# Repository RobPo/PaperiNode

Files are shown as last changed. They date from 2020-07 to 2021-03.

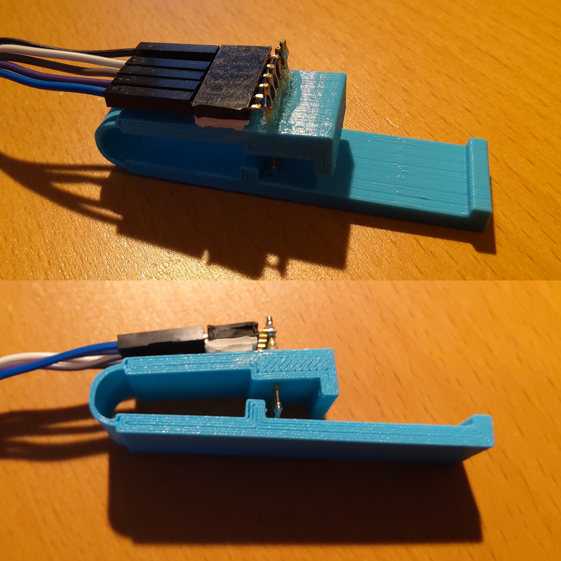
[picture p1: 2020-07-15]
3d/programming clip/programming_clip_2.jpg

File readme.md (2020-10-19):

Solar powered E-Paper Node for LoRaWAN
===============================================================

Welcome to the docs! This is an Arduino Library for PaperiNode, a TTN-connected 1.1” E-Paper Node which is powered by ambient light and thus energy-autark. 

paperinodes
[*PaperiNode*](https://twitter.com/Paperino_io)

Hardware specification (**[Datasheets](https://github.com/RobPo/paperinode/tree/master/datasheets)**):
-----------------------
- MCU: ATmega328pb (16MHz, 32KB FLASH, 2KB SRAM)
- External RTC: MCP7940M
- LoRa Chip: RFM95W, Antenna EU_863_870 or u.FL connector for external antenna
- EPD: 1.1" Plastic Logic, 148x70pixel
- Flash: Winbond W25X40Cl, 4Mbit
- Low power design: Deep Sleep 2.4uA
- PV cells: IXYS SLMD121H04L
- Energy-harvesting PMIC: E-Peas AEM10941 w/ MPPT
- Storage device: EDLC supercap 400mF

### Revisions

  
The second revision (black FPC) is the successor of the first edition (white FPC) and contains the following changes:
- Reduced deep sleep current
- SPI pins exposed on bottom side to connect external sensors etc.
- SPI flash added to store measurement data or upto seven pictures

How To Use
-------------------

### Installation

Please download and start the latest Arduino IDE. Select "Pololu A-star 328pb, 5V/16MHz" in the menu Tools/Board; if not available please add to File>Preferences>Additional Boards Manager URL the following source "https://files.pololu.com/arduino/package_pololu_index.json". Now please download and import the examples of this repository.

### Hardware hookup

To program PaperiNode you will need to connect a FTDI programmer (USB to Serial, available for ~3€ e.g. at eBay) to the exposed pins on the bottom side. The most reliable version is to solder a pin row and connect everything on a breadboard. Alternatively, its possible to connect the programmer  directly to the bottom pins (if needed in combination with a slight pressure) or to 3D-print your own pogo-pin based clamp (see below):
Programming the device

### E-Ink display library 'PL_microEPD'

Based on Adafruit GFX library, this version of 'PL_microEPD' enables the easy usage of the 1.1" EPD in combination with the used MCU ATmega328PB. Most work was done around coping with the limited available SRAM size while still exposing all the nice features of the screen. The following commands are available:

```C++
void begin();                                       // Initializes and clears the screen
void clear();                                       // Clears the framebuffer	
void printText(String text, int x, int y, int s);   // Write text to a defined position with size s
void loadFromFlash(int address=ADDR_FRAMEBUFFER, bool toPreviousBuffer=true);	   // Loads a previously stored pic from SPI flash
void fillRectLM(int16_t x, int16_t y, int16_t w, int16_t h, uint16_t color);           // Draws a filled rectangle
void update(int updateMode=EPD_UPD_FULL);           // Trigger an update with the framebuffer content
void end(void);                                     // De-init the screen to save power
```

The screen supports four different greylevels:

```C++
#define EPD_BLACK 0x00            // A black almost as dark as the night
#define EPD_DGRAY 0x01            // A darker gray
#define EPD_LGRAY 0x02            // A lighter gray
#define EPD_WHITE 0x03            // A white as bright as snow
```

The following update modes are available:
```C++
#define EPD_UPD_FULL  0x00            // Triggers a Full update, 4 GL, 800ms
#define EPD_UPD_PART  0x01            // Triggers a Partial update, 4 GL, 800ms
#define EPD_UPD_MONO  0x02            // Triggers a Partial Mono update, 2 GL, 250ms
```
### Examples

Now its time to get started! Ready to use examples can be found **[here](https://github.com/RobPo/paperinode/tree/master/examples)**:

- 01_SerialPrintDevEUI > Prints the individual Device EUI address to the serial console. 
- 02_Hello World 	   > Shows the first text on the epd screen.
- 03_SaveImgToFlash    > Shows how to store upto seven pictures in the flash memory.
- 04_MeasVScap 		   > Example which prints the measured voltage of the supercap storage device on the epd screen.
- 05_Minimal 		   > Demonstrates a simple counter, being updated everytime if there is sufficient energy harvested. The supercap voltage v_scap is measured minutely while the ATmega328pb processor is in deep sleep all remaining time. Triggering is done via external RTC to minimize current consumption during deep sleep phase. IF the voltage is charged above a certain limit (ie 4.2V), an image update is triggered. 
- 06_WeatherForecast   > Based on the previous demo,  a LoRa up- and downlink is added; the received payload is then shown on the screen.

Power consumption
-------------------

For this example the used energy is 0,7Joule (based on ABP with SF7 and 18byte payload within downlink). 

Projects
-------------------
Following demo projects are for your inspiration! What will you implement with PaperiNode? Tell us, we’ll love to add your project here!

weatherforecast

Where To Get
-------------------
PaperiNode is available at [tindie](https://www.tindie.com/products/robertposer/paperinode-solarpowered-e-paper-node-for-lorawan/)


License Information
-------------------

This library is **open source**!

Libraries used in this sketch are based on the LoRaWAN stack from IDEETRON/NEXUS, for more infos please check this great source: https://github.com/Ideetron/Nexus-Low-Power

Libraries used in this sketch around the ePaper and the Example sketches are created by Robert Poser, Jun 20th 2020, Dresden/Germany. 

Released under GNU Lesser General Public License, either version 3 of the License, or (at your option) any later version, check license.md for more information.

We invested time and resources providing this source code, please support open source hardware and software @Ideetron, @Adafruit, @Watterott, @Tindie and others.

If you like this project please [follow us on Twitter](https://twitter.com/paperino_io).
Having problems or have awesome suggestions? Contact us: paperino.display@gmail.com.

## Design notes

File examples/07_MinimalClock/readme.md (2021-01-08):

Example: 07_Clock demo
-------------------
Updates every five minutes. Should run around the clock if exposed to the window desk (battery-free).
Sketch optimized for low power usage on MCU and EPD level.



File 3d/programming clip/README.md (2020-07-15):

Build Instructions
==================

After printing, heat up the end to bend the clip open. Insert the Pogo PINs and heat it up again to bend it back.

Images
======
programming_clip_2

Thanks to SebastianHa for creating. https://github.com/sebastianha/lorapaper/tree/master/utils/programming%20clip

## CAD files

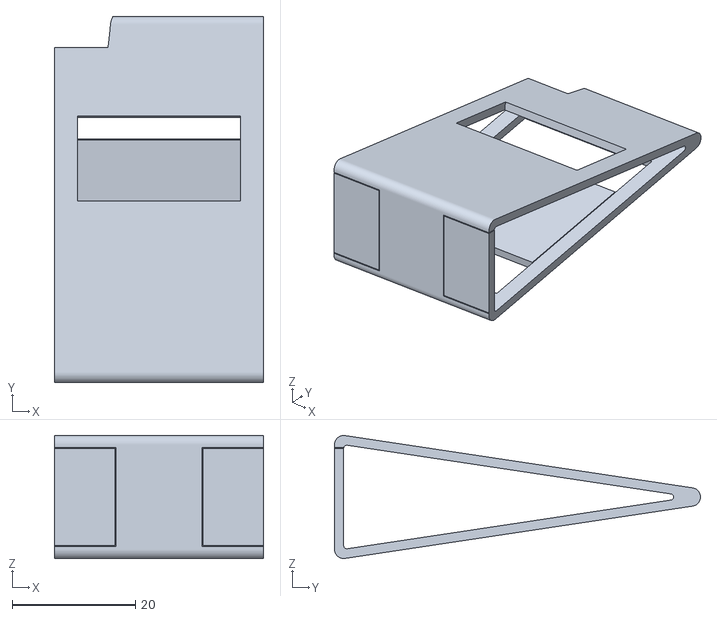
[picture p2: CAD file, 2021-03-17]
3d/housing/PaperiNode_V3_with_Breakaway.stl
34.0 x 59.5 x 20.0

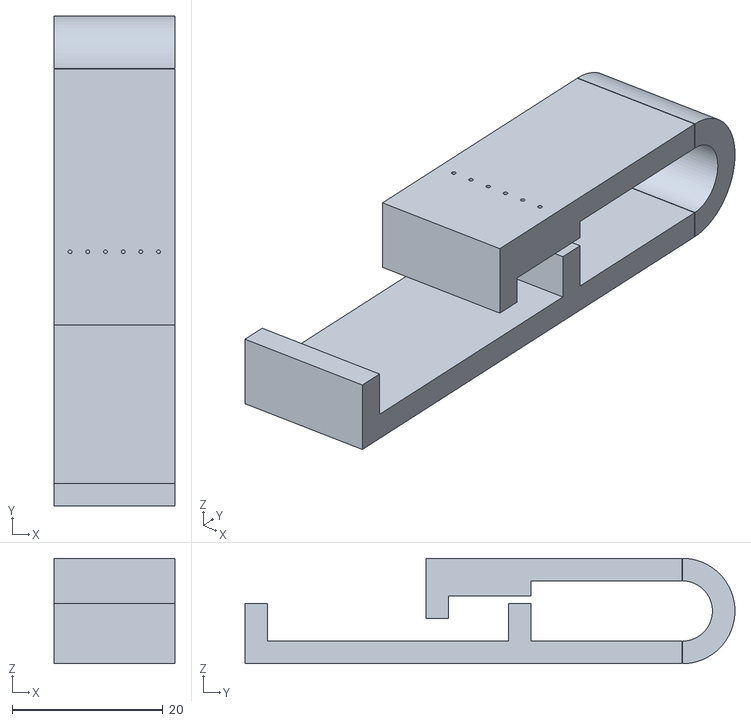
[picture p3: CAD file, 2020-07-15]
3d/programming clip/Paper Node Programming Clip.stl
16.0 x 65.0 x 14.0

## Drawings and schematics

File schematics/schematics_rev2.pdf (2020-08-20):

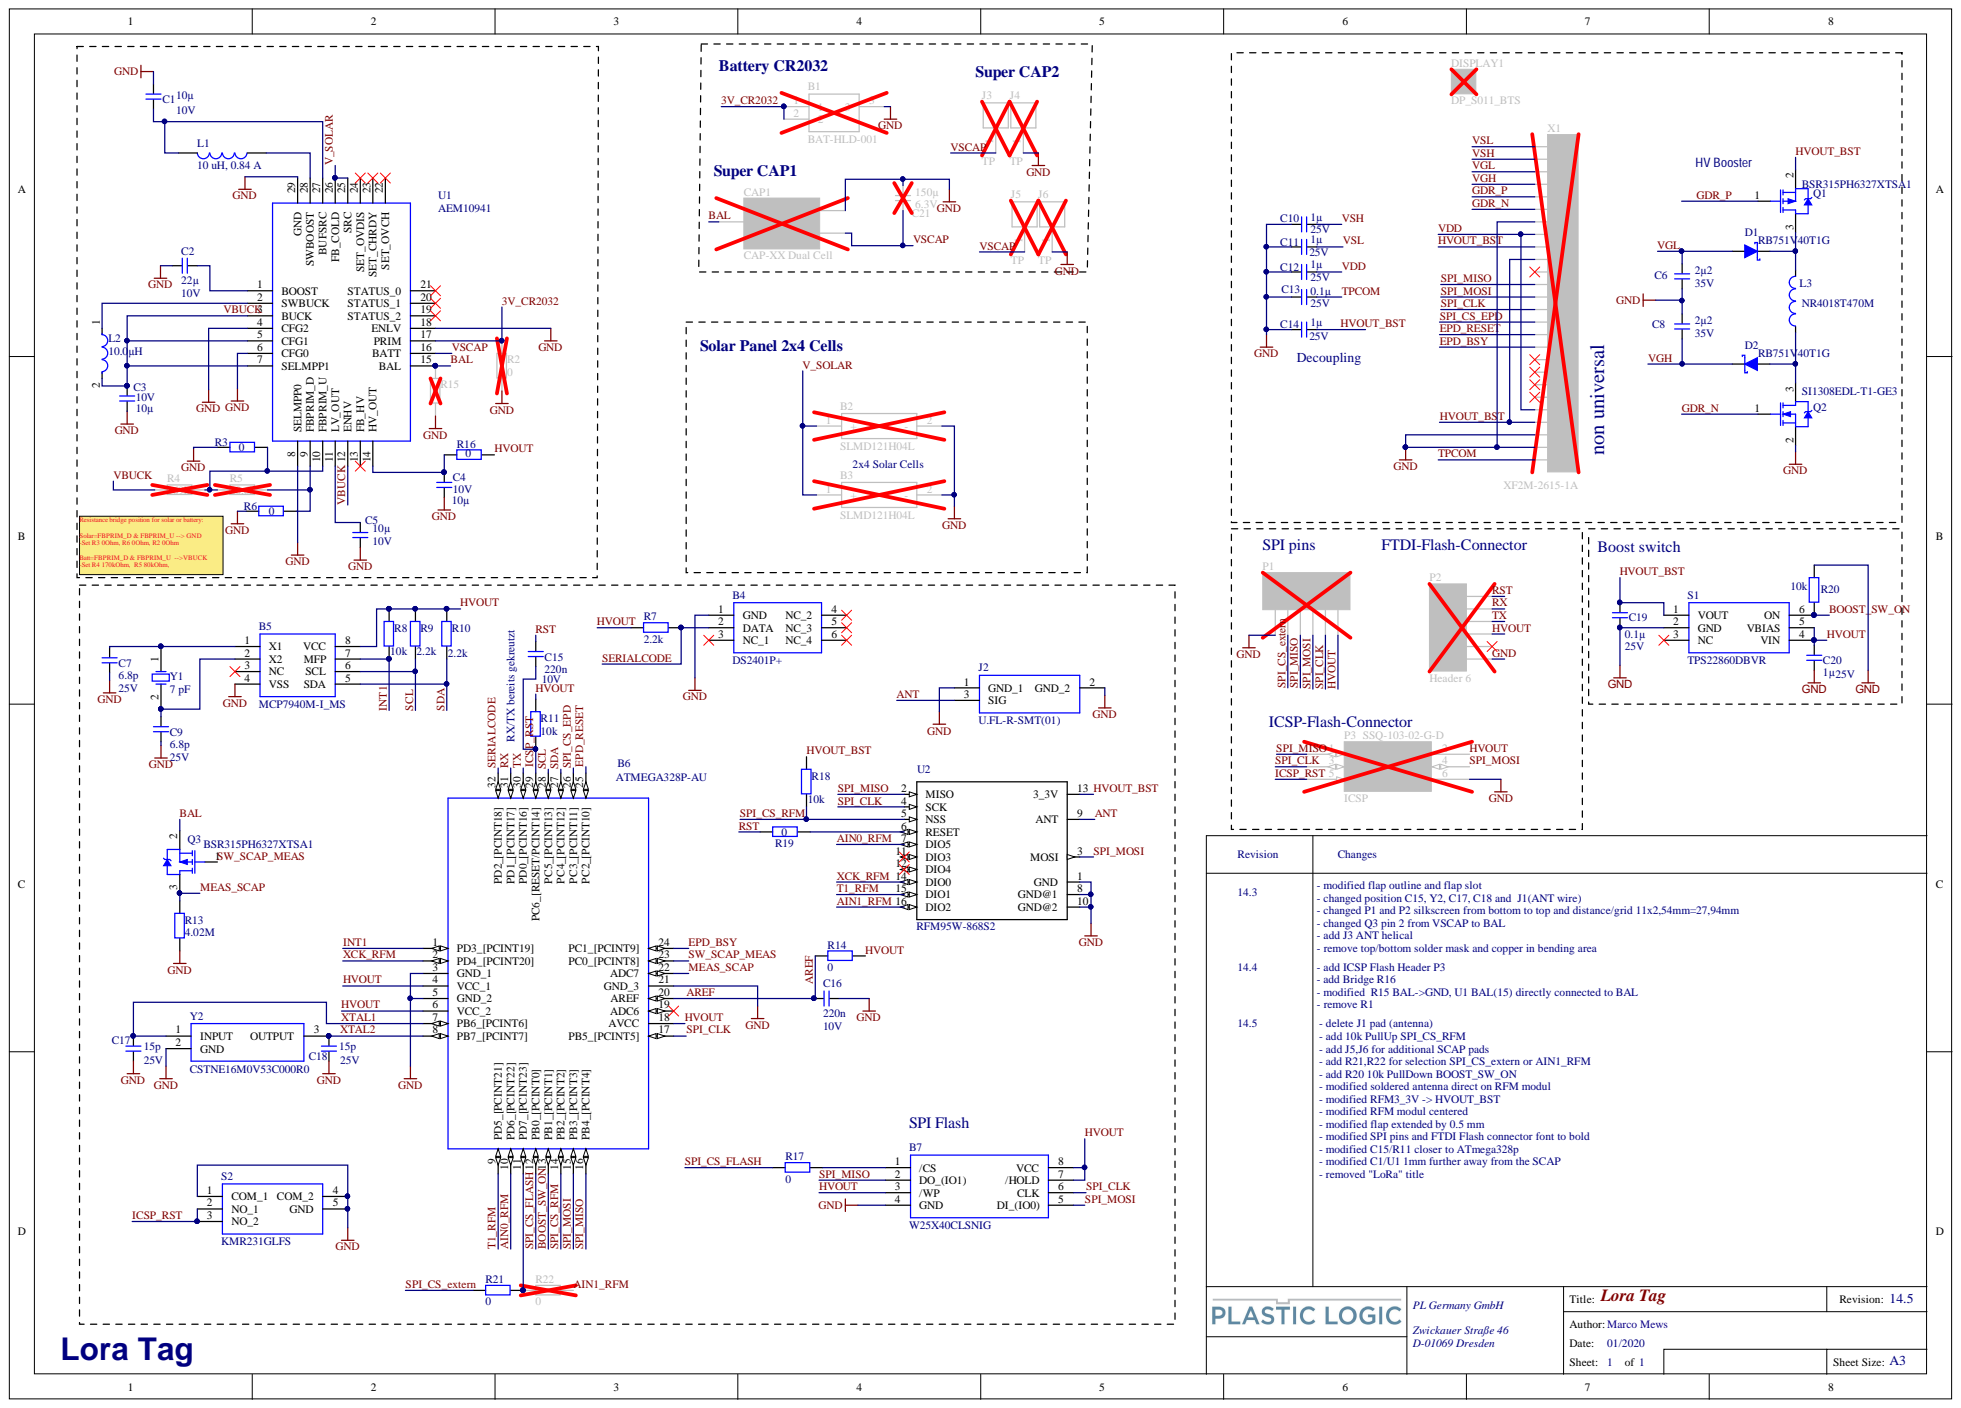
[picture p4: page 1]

CAP-XX Dual Cell

Resistance bridge position for solar or battery:

RX/TX bereits gekreutzt

- changed position C15, Y2, C17, C18 and J1(ANT wire)
- changed P1 and P2 silkscreen from bottom to top and distance/grid 11x2,54mm=27,94mm
- changed Q3 pin 2 from VSCAP to BAL
- add J3 ANT helical
- remove top/bottom solder mask and copper in bending area

- add Bridge R16
- modified R15 BAL->GND, U1 BAL(15) directly connected to BAL
- remove R1

- add 10k PullUp SPI_CS_RFM
- add J5,J6 for additional SCAP pads
- add R21,R22 for selection SPI_CS_extern or AIN1_RFM
- add R20 10k PullDown BOOST_SW_ON
- modified soldered antenna direct on RFM modul
- modified RFM3_3V -> HVOUT_BST
- modified RFM modul centered
- modified flap extended by 0.5 mm
- modified SPI pins and FTDI Flash connector font to bold
- modified C15/R11 closer to ATmega328p
- modified C1/U1 1mm further away from the SCAP
- removed "LoRa" title

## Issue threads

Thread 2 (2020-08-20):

Hardware design files missing

Kater--S, 2020-08-20:
In order to further develop for the hardware, it would be helpful to have at least a schematic so we can understand the device's mode of operation.
Unfortunately all hardware design files are missing on the Tindie page as well as here in the repo.

sBooz, 2020-08-20:
I found some information here: https://www.hackster.io/news/this-incredible-battery-free-lora-epaper-display-is-flexing-on-your-pcb-construction-techniques-e855909f135a

RobPo, 2020-08-20:
The schematic can be found here: https://github.com/RobPo/PaperiNode/tree/master/schematics The de-activated components are optional (e.g. battery CR2032) or soldered by hand (e.g. PV cells).

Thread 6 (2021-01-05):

Date not correctly processed [06_WeatherForecast.ino]

cyberman54, 2021-01-05:
PaperINode Display is showing `254.65.` in line1, after succesful receiving data from node red flow.

RobPo, 2021-01-05:
Hi @cyberman54 in the beginning I reserved only one byte for transmitting the date, and had the "dayofyear" function used to transmit and calculate the correct dd.mm format. That worked last year pretty well until somewhere in mid-august... after the 255th day of 2020 that didn't work anymore and I de-activated showing the date...
Need to think a bit about that... maybe you have an idea too? Can't easily increase the payload size for trasnmitting more date data since I need to be sure the currently running PaperiNodes still continue to run...

cyberman54, 2021-01-05:
maybe using unix time? That would be 4 bytes total for date and time.

RobPo, 2021-01-16:
Actually a working fix was already implemented by transmitting the day and month as one byte each (ignoring the year):
- day: lora.RX.Data[2]
- month: lora.RX.Data[17]
Please let me know if you still see this issue.

cyberman54, 2021-01-17:
Corrections in TTN encoder and NodeRed decoder were still missing.
Solved by https://github.com/RobPo/PaperiNode/pull/8

Closed 2021-01-17.

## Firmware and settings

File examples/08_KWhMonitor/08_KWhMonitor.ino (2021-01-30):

/****************************************************************************************
* This example demonstrates a simple kWh monitor demo, based on an optocoupled smart meter 
* reader which sends periodically the present kWh reading to the TheThingsNetwork console 
* via Node-Red flow. Everytime PaperiNode wakes up (+3hrs) and syncs with the TTN-backend
* its triggers a download of the last measured kWh reading (respecting the fair use policy)
/****************************************************************************************
* File:               kWhMonitor.ino
* Author:             Robert Poser
* Created on:         27-01-2021
* Supported Hardware: PaperiNode (with RFM95, PV cell, supercap & 1.1" EPD)
* 
* Libraries used in this sketch are based on the LoRaWAN stack from IDEETRON/NEXUS, for 
* more infos please check this great source: https://github.com/Ideetron/Nexus-Low-Power
* 
* You should have received a copy of the GNU Lesser General Public License
* along with this program.  If not, see <http://www.gnu.org/licenses/>.
****************************************************************************************/

#include "paperinode.h"
#include "mcp7940.h"
#include "DS2401.h"
#include "spi_flash.h"
#include "RFM95.h"
#include "LoRaMAC.h"
#include "lorawan_def.h"
#include "Cayenne_LPP.h"
#include "PL_microEPD44.h"

/******** GLOBAL VARIABLES ****************************************************************/
sAPP    app;                  // Application variable
sLoRaWAN  lora;               // See the lorapaper.h file for the settings 
sTimeDate TimeDate;           // RTC time and date variables
LORAMAC lorawan (&lora);      // Initialize the LoRaWAN stack.  
CayenneLPP LPP(&(lora.TX));   // Initialize the Low Power Protocol functions
PL_microEPD epd(EPD_CS, EPD_RST, EPD_BUSY);    //Initialize the EPD.

volatile bool RTC_ALARM = false;        // Interrupt variable
uint16_t v_scap, ndr;   
uint16_t kWh[7];

/********* INTERRUPTS *********************************************************************/
ISR(INT1_vect) {                // Interrupt vector for the alarm of the MCP7940 Real Time 
  RTC_ALARM = true;             // Clock. Do not use I2C functions or long delays
}                               // here.

ISR(TIMER1_COMPA_vect) {        // Interrupt vector for Timer1 which is used to time the Join  
  lora.timeslot++;              // and Receive windows for timeslot 1 and timelsot 2 Increment 
}                               // the timeslot counter variable for timing the

/********* MAIN ***************************************************************************/
void setup(void) {  
  analogReference(EXTERNAL);          // use AREF for reference voltage
  SPI.begin();                        // Initialize the SPI port
  SPI.beginTransaction(SPISettings(8000000, MSBFIRST, SPI_MODE0));
  
  pinMode(SW_TFT, OUTPUT);            // Switch for V_Scap
  pinMode(DS2401, OUTPUT);            // Authenticating IC DS2401p+
  pinMode(RFM_NSS, OUTPUT);           // RFM95W NSS = CS
  pinMode(SPI_FLASH_CS, OUTPUT);      // External SPI flash
  digitalWrite(DS2401, HIGH);         // to save power...
  digitalWrite(SW_TFT, HIGH);         // to save power...
  digitalWrite(SPI_FLASH_CS, HIGH);   // to save power...

  epd.begin();                        // Turn ON & initialize 1.1" EPD
  epd.loadFromFlash(ADDR_PIC1, 0);    // Load an pic from external flash
  epd.saveFBToFlash(ADDR_FRAMEBUFFER);// And save it to external framebuffer on flash
  epd.update();                       // Update EPD
  epd.end();                          // to save power...
  digitalWrite(RFM_NSS, LOW);         // to save power...
  flash_power_down();                 // To save power...
  SPI.endTransaction();               // to save power...
  SPI.end();                          // to save power...
 
  I2C_init();                         // Initialize I2C pins
  mcp7940_init(&TimeDate, app.LoRaWAN_message_interval);   // Generate minutely interrupt 

  v_scap = analogRead(A7);            // 1st Dummy-read which always delivers strange values...(to skip)
  RTC_ALARM = true;
}

void loop(){ 
    if(RTC_ALARM == true){             // Catch the minute alarm from the RTC.       
        mcp7940_reset_minute_alarm(app.LoRaWAN_message_interval);        
        mcp7940_read_time_and_date(&TimeDate);    
          
        digitalWrite(SW_TFT, LOW);     // Turn ON voltage divider 
        delay(1);                      // To stabilize analogRead
        v_scap = analogRead(A7);       // Measure V_scap
        digitalWrite(SW_TFT, HIGH);    // Turn OFF voltage divider 
  
        if (v_scap >= 574) {           // Proceed only if (Vscap > 3,8V)--> DEFAULT for 1.5F!
          if (++app.Counter%3==1) {       // Every three hours... 
               app.LoRaWAN_message_interval=58;

            LPP.clearBuffer();         // Form a payload according to the LPP standard to 
            LPP.addDigitalOutput(0x00, app.Counter);
            LPP.addAnalogInput(0x00, v_scap*3.3/1024*2);

            SPI.begin();
            SPI.beginTransaction(SPISettings(4000000, MSBFIRST, SPI_MODE0));
            epd.begin(false);             // Turn ON EPD without refresh to save power
            lorawan.init();               // Init the RFM95 module

            delay(50);
            lora.RX.Data[1] = 0;         // Dummy value to check lateron if downlink data was received
            lorawan.LORA_send_and_receive();  // LoRaWAN send_and_receive
            if (lora.RX.Data[1] == 0)    // Downlink data received?
                ndr++;                    // if not increase nodatareceived (ndr) counter                      

            epd.loadFromFlash(ADDR_FRAMEBUFFER);        // Load last image to pre-buffer
            epd.printText("kWh-Monitor ", 1, 2, 1);         // Header line
            
            String leadingDay = "";
            if (lora.RX.Data[0] < 10)
              leadingDay = "0";

            String leadingMonth = "";
            if (lora.RX.Data[1] < 10)
              leadingMonth = "0";  
            epd.printText(leadingDay + String(lora.RX.Data[0]) + "." + leadingMonth + String(lora.RX.Data[1])+ ".", 70, 2, 1);

            String leadingHour = "";
            if(lora.RX.Data[2] < 10) 
              leadingHour = " ";
            
            String leadingMinute = "";
            if(lora.RX.Data[3] < 10) 
              leadingMinute = "0";
            epd.printText(leadingHour + String(lora.RX.Data[2]) + ":" + leadingMinute + String(lora.RX.Data[3]), 110, 2, 1);

            for (int i=1; i<7; i++)
              kWh[i]=kWh[i-1];
            kWh[0] = lora.RX.Data[4];
            char PufferChar[4];
            dtostrf(kWh[0]/100.0, 3, 1,PufferChar);
            epd.printText(String(PufferChar) + "kWh", 0, 17, 3);  // kWh

            String leadingCt = "";
            if (kWh[0]/100*30<100)
              leadingCt = " ";
            if (kWh[0]/100*30<10)
              leadingCt = "  ";
            epd.printText(leadingCt + String(kWh[0]/100*30) + "ct", 0, 47, 3);  // Cost

            epd.printText("V " + String(v_scap*3.3/1024*2, 1), 115, 17, 1); // Plot last known voltage
            epd.printText("U " + String(app.Counter/3+1)      , 115, 26, 1); // Plot how many syncs have been tried
            epd.printText("D " + String(app.Counter/3+1 - ndr+1), 115, 35, 1); // Plot how many downlinks were empty
 
            epd.fillRectLM(92, 44, 4, 1, EPD_BLACK);
            epd.fillRectLM(97, 44, 4, 1, EPD_BLACK);
            epd.fillRectLM(102, 44, 4, 1, EPD_BLACK);
            epd.fillRectLM(107, 44, 4, 1, EPD_BLACK);
            epd.fillRectLM(112, 44, 4, 1, EPD_BLACK);
            epd.fillRectLM(117, 44, 4, 1, EPD_BLACK);
            epd.fillRectLM(122, 44, 4, 1, EPD_BLACK);
            
            epd.fillRectLM(92, 42, 4, kWh[0]/6, EPD_BLACK);
            epd.fillRectLM(97, 42, 4, kWh[1]/6, EPD_BLACK);
            epd.fillRectLM(102, 42, 4, kWh[2]/6, EPD_BLACK);
            epd.fillRectLM(107, 42, 4, kWh[3]/6, EPD_BLACK);
            epd.fillRectLM(112, 42, 4, kWh[4]/6, EPD_BLACK);
            epd.fillRectLM(117, 42, 4, kWh[5]/6, EPD_BLACK);
            epd.fillRectLM(122, 42, 4, kWh[6]/6, EPD_BLACK);
       
            epd.saveFBToFlash(ADDR_FRAMEBUFFER);
            if (v_scap > 640)                                   // IF V_scap > 4.2V
              epd.update();                                     // Trigger a 900ms default update (4GL)
            else
              epd.update(EPD_UPD_MONO);                         // Trigger a 450ms low power update (2GL)

            epd.end();                                           // To save power...
            digitalWrite(RFM_NSS, LOW);                          // To save power...
            flash_power_down();                                  // To save power...
            SPI.endTransaction();                                // To save power...
            SPI.end();                                           // To save power...
          }
        }
        RTC_ALARM = false;             // Clear the boolean.
      } else
        LowPower.powerDown(SLEEP_FOREVER, ADC_OFF, BOD_OFF);      // To save power... 
}

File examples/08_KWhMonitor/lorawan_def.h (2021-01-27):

/******************************************************************************************
* Copyright 2017 Ideetron B.V.
*
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
* You should have received a copy of the GNU Lesser General Public License
* along with this program.  If not, see <http://www.gnu.org/licenses/>.
******************************************************************************************/
/****************************************************************************************
* File:     Struct.h
* Author:   Gerben den Hartog
* Company:	Ideetron B.V.
* Website:  http://www.ideetron.nl/LoRa
* E-mail:   info@ideetron.nl
* Created on:         06-02-2017
* Supported Hardware: ID150119-02 Nexus board with RFM95
****************************************************************************************/


#ifndef STRUCT_H
#define STRUCT_H

	#include <stdint.h>
	#include <stdbool.h>

	#define LORA_FIFO_SIZE			64
	#define CFLIST_FREQUENCIES_MAX	5
	#define DEFAULT_FREQUENCIES		3
	#define LORAWAN_MAX_PAYLOAD		52
	
	/*********************************************************************************************
										ENUMERATION DEFENITIONS
	*********************************************************************************************/
	// LoRaWAN Mote class specification
	typedef enum
	{
		CLASS_A,
		//CLASS_B,
		CLASS_C
	}eLoRaWAN_MOTE_CLASS;
		
	// Enumeration to set the used back-end and use the TX and RX settings for that particular back-end.
	typedef enum
	{
		MANUAL,				//	Manual mode for setting the TX and RX channels and data rate for OTAA and data messages
		SEMTECH,			//	Semtech's the patent holder for the LoRaWAN chips.
		The_Things_Network,	//	The Things Industries back-end, which is only functional for OTAA motes. ABP is barely supported and the service may have some downtime from time-to-time for maintenance.
		KPN					//	The Dutch full-coverage LoRaWAN network provider in the Netherlands, which has LoRaWAN localization capabilities, but it's services come at a  cost.  	
	}eBACKENDS;

	/* MAC HEADER types */
	typedef enum 
	{
		JOIN_REQUEST            = 0x00, // 0000 0000
		JOIN_ACCEPT             = 0x20, // 0010 0000
		UNCONFIRMED_DATA_UP     = 0x40, // 0100 0000
		UNCONFIRMED_DATA_DOWN   = 0x60, // 0110 0000
		CONFIRMED_DATA_UP       = 0x80, // 1000 0000
		CONFIRMED_DATA_DOWN     = 0xA0, // 1010 0000 
		CONFIRMED_BITMASK		= 0x80,
		UNCONFIRMED_BITMASK		= 0x40,
		INIT_VAL				= 0x00
	}eMESSAGE_TYPES;
	
	// Receive delay enumeration for OTAA Join Delay and message delays.
	typedef enum 
	{
 		JOIN_DELAY_1   = 4900,
 		JOIN_DELAY_2   = 5900,
		RECEIVE_DELAY1 = 900,
		RECEIVE_DELAY2 = 1900	
	}eRECEIVE_DELAY;


	// Direction enumeration for the MIC calculation. See page 20, chapter 4.3.3 of the Lora Specification 1.02
	 typedef enum
	 {
		 UPSTREAM_DIR    = 0,    //  Uplink   (Away from mote)
		 DOWNSTREAM_DIR  = 1     //  Downlink (towards the mote)
	 }eDIRECTION;

	// LoRaWAN Datarates
	typedef enum
	{
		SF12_BW125kHz = 0x01,
		SF11_BW125kHz = 0x02,
		SF10_BW125kHz = 0x03,
		SF09_BW125kHz = 0x04,
		SF08_BW125kHz = 0x05,
		SF07_BW125kHz = 0x06,
		SF07_BW250kHz = 0x07,
		SF09_BW500kHz = 0x08,
		SF_BITMASK    = 0x03
	}eLoRaWAN_DATARATES;
	
	// Channel enumeration 
	typedef enum
	{
		CH00_868_100,
		CH01_868_300,
		CH02_868_500,
		CFLIST_INDEX_1,
		CFLIST_INDEX_2,
		CFLIST_INDEX_3,
		CFLIST_INDEX_4,
		CFLIST_INDEX_5,
		CH03_867_100,
		CH04_867_300,
		CH05_867_500,
		CH06_867_700,
		CH07_867_900,
		CH10_869_525
	}eLoRaWAN_CHANNELS;
	
	// Confirmed and unconfirmed messages type enumeration.
	typedef enum
	{
		UNCONFIRMED,
		CONFIRMED
	}eCONFIRMATION;
	
	// Activation methods
	typedef enum
	{
		ACTIVATION_BY_PERSONALISATION,
		OVER_THE_AIR_ACTIVATION
	}eMOTE_NETWORK_JOIN;

	//return values for the RFM95
	typedef enum
	{
		INIT,				//0 	Initialization error return code
		CRC_OK,				//1		CRC of the received message is incorrect, indicating an incomplete or corrupted message
		CRC_NOK,			//2		CRC of the received message is correct
		MIC_OK,				//3		Message Integrity Checksum is correct.
		MIC_NOK_OTAA,		//4		MIC of the OTAA message is incorrect.
		MIC_NOK_MESSAGE,	//5		MIC of the received message is incorrect.
		ADDRESS_OK,			//6		Device address of the received message matches that of this LoRaWAN mote.
		ADDRESS_NOK,		//7		The device address of the received message doesn't match to the dev address of this mote.	
		MAC_HEADER_NOK,		//8		Message header has an incorrect value, not matching any LoRaWAN headers
		RX_TIMEOUT,			//9		The RFM hasn't receive any message and got a time-out instead.
		OTAA_POINTER,		//10	Over The Air Activation structure has an incorrect pointer
		RX_MESSAGE,			//11	Message received.
		OTAA_COMPLETE,		//12	OTAA has been successfully completed.
		NEW_MESSAGE,		//13	When a new message has been received.
		DEFAULT_MAC,		//14	When a message is received with an invalid MAC header, this return value will be send back.	
		LORA_POINTER_INVALID//15	Invalid Lora pointer
	}RFM_RETVAL;
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

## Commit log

2020-06-30 Changed wakeup freq to 2hrs
    plus typo corrected
    [06_WeatherForecast.ino, lorawan_def.h]
2020-07-10 power consumption added
2020-07-15 programming clip 3d files
    [Paper Node Programming Clip.stl]
2020-08-31 intro pic & date added
    Weather demo sketch cleaned up, intro picture added after reset, date added (next to existing timestamp)
    [03_SaveImgToFlash.ino, 05_Minimal.ino, 06_WeatherForecast.ino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]
2020-11-19 low power update mode added
    Enabled saving of framebuffer on external flash during power off
2021-01-10 Vscap changed
    voltage limits extended
2021-01-12 Hour mask fixed
    Changed MASK_HOUR from 0x10 to 0x30
    [07_MinimalClock.ino]
2021-01-14 Hour bug fixed hopefully
    Fixed hopefully the strange hour-bug
    [07_MinimalClock.ino]
2021-01-16 Update nodeRED_weatherFlow.txt
    negative object-data (temperature) not directly supported by TTN... causes rejection of complete weather-data downlink. manual workaround fixes this problem.
2021-01-17 Update encoder.h
    Repair broken date display
2021-02-13 Update 07_MinimalClock.ino
    Select update rate dynamically based on supercap voltage level
2021-02-13 Revert "Update 07_MinimalClock.ino"
    This reverts commit 447d8de62b01cb2440d633ec7734a6dc4bb69e99.
    [07_MinimalClock.ino]
2021-02-13 Update 07_MinimalClock.ino
    Added dynamic update rate depending on supercap voltage
2021-03-17 3d sketch added
    [Paper Node Programming Clip.stl, PaperiNode_V3_with_Breakaway.stl]

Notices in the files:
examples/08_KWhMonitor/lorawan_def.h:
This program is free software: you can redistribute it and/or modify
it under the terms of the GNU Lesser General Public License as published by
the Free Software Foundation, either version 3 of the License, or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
